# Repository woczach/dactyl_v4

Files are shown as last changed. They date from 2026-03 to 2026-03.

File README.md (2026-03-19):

# Dactyl v4

Custom split ergonomic keyboard project based on a Dactyl Manuform-style shell, adapted around a flexible main PCB, a custom thumb cluster, and trackball support.

This repository contains the KiCad design files, printable case parts, and reference images used during the build.

## Overview

This project is my own Dactyl-style keyboard design. The main board is a custom flexible PCB, while the extra keys and thumb-cluster approach were informed by an existing open hardware reference.

Design references used for this build:

- Dactyl Manuform base shape and layout:
[ryanis.cool keyboard link](https://ryanis.cool/cosmos/beta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)
  
- Extra keys for thumb-cluster:
  [MxLEDBitPCB](https://github.com/swanmatch/MxLEDBitPCB/blob/master/readme_en.md)

## Gallery

### 3D keyboard visualization

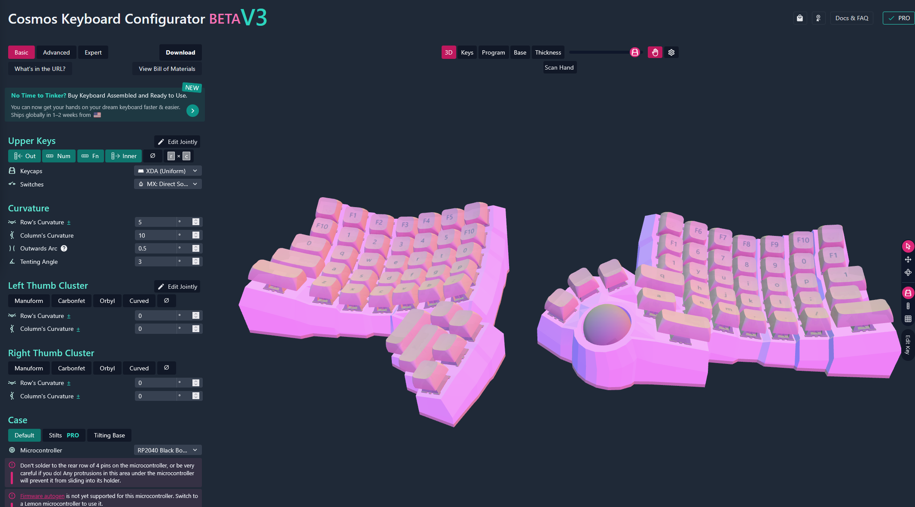
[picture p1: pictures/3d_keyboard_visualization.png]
3D keyboard visualization


### Main flexible PCB

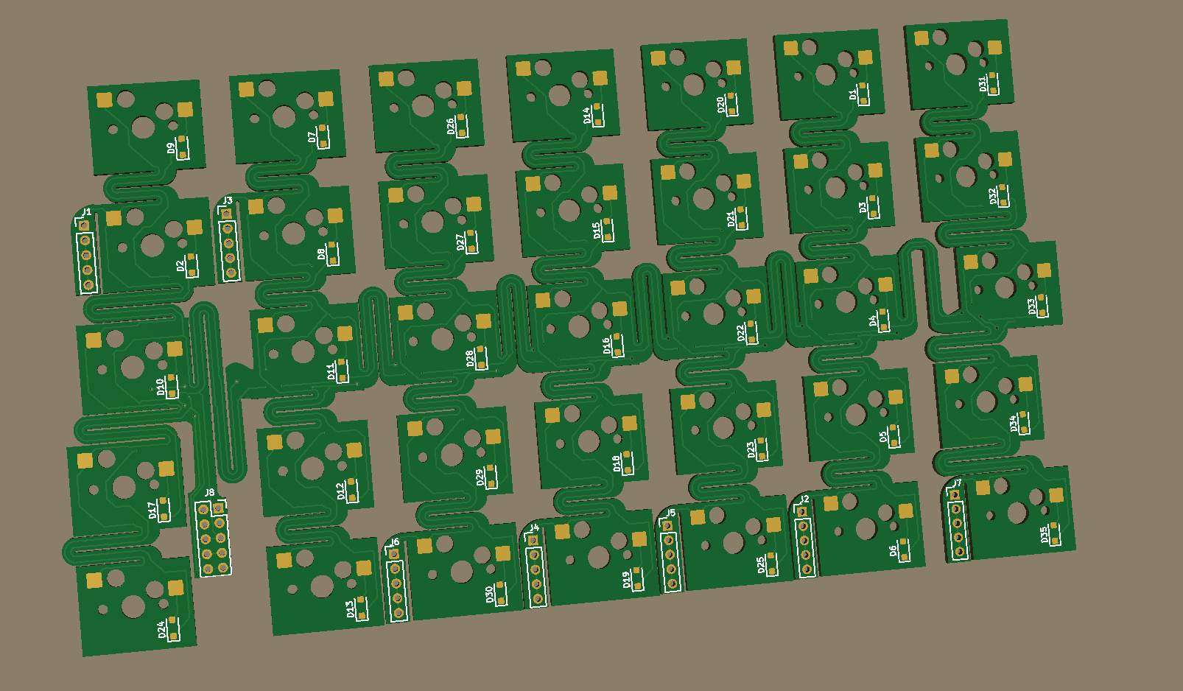
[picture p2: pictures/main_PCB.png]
Main PCB


### Extra keys / thumb cluster reference

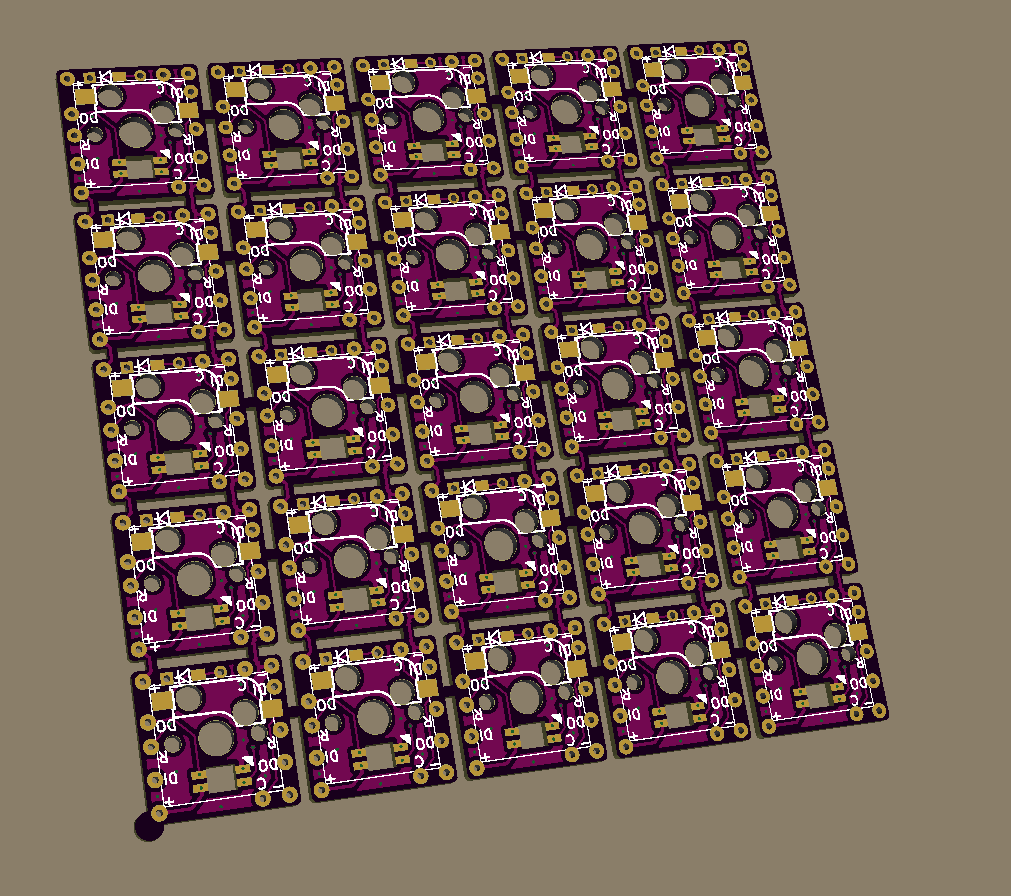
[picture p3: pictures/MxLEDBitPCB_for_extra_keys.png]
MxLEDBitPCB reference for extra keys


## Repository Contents

- `dactyl_v4/3dForm/printfiles/` contains the printable case, plate, and holder STL files.
- `dactyl_v4/Kicad/flex/` contains the main KiCad project for the flexible PCB design.
- `pictures/` contains reference renders and PCB images used in this README.

## Hardware Summary

- Split ergonomic Dactyl-style keyboard
- Custom flexible main PCB
- Separate thumb / extra-key area inspired by MxLEDBitPCB
- Trackball support using a PMW3360 or PMW3389 sensor
- Dual RP2040 controller setup with TRRS interconnect

## Bill of Materials

Prices below reflect the sourced parts actually purchased for this build. Items not covered by that list are left blank.

| Category | Item | Qty | Notes | Total |
| --- | --- | ---: | --- | ---: |
| Keys and switches | Womier Retro Brown Gray PBT keycap set | 1 | 138-key Cherry-profile set | 51.39 PLN |
| Keys and switches | PBTfans Doppelganger 40s kit | 1 | Child kit, 40s | 77.19 PLN |
| Keys and switches | MX-compatible switches | 90 | Outemu Silent Cream Yellow Pro, bought as one 90-pack | 71.19 PLN |
| Keys and switches | 1N4148 diodes | 100 | 1N4148W T4 SOD-123, bought as one 100-pack | 5.72 PLN |
| Pointing device and mechanical parts | 34 mm trackball | 1 | GBALL34RN, purple | 47.79 PLN |
| Pointing device and mechanical parts | PMW3360 or PMW3389 sensor | 1 | PMW3389 module | 69.19 PLN |
| Pointing device and mechanical parts | 3 x 6 x 2.5 mm bearings | 5 | Bought as one 5-pack | 9.41 PLN |
| Pointing device and mechanical parts | 3 x 8 mm dowel pins | 10 | M3, bought as one 10-pack | 4.90 PLN |
| Pointing device and mechanical parts | Tindie-supported PCB for sensor assembly | 1 | Use a compatible board as required by the sensor setup |  |
| Electrical | RP2040 Black Board USB-C | 2 | Aliexpress boards |  |
| Electrical | PJ-320A TRRS connectors | 10 | Bought as one 10-pack | 6.29 PLN |
| Electrical | TRRS cable | 1 | 3.5 mm TRRS spring coiled cable, 90-degree male-to-male | 13.99 PLN |
| Electrical | Flexible PCB fabrication | 1 | Main flex PCB, converted from 30 USD | 110.61 PLN |
| Electrical | Extra PCB fabrication | 1 | Auxiliary PCB, converted from 2 USD | 7.37 PLN |
| Electrical | Kailh hot-swap sockets | 3 | 40-piece packs, CPG1511 | 45.03 PLN |
| Electrical | SK6812MINI-E LEDs | 1 | 100-piece lot | 34.89 PLN |
| Electrical | Wire-wrap or magnet wire spool | 1 | Internal wiring |  |
| Mounting | M3 x 6 mm flat head screws | 18 | Bottom plate and microcontroller holder |  |
| Mounting | M3 x 8 mm flat head screws | 2 | Microcontroller holder through bottom plate |  |
| Mounting | M3 screw inserts | 20 | Heat-set or press-fit, depending on print and process |  |
| Other parts | 3D print service | 1 | Case and related printed parts | 100.00 PLN |

**Summary price:** 654.96 PLN

## Attribution

This repository is a custom project, but it explicitly builds on ideas and references from the following sources:

- Ryanis Cosmos for the Dactyl Manuform base geometry and layout exploration
- Swanmatch MxLEDBitPCB for ideas around extra keys and thumb-cluster implementation

The main board design in this repository is my own custom flexible PCB adaptation.

## License

This repository is distributed under the license included in [LICENSE](LICENSE).

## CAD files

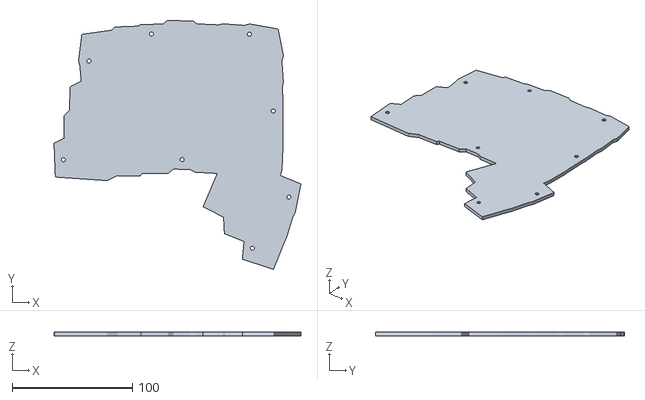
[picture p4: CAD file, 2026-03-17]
dactyl_v4/3dForm/printfiles/woboard_v4-plateleft.stl
205.4 x 206.9 x 3.00

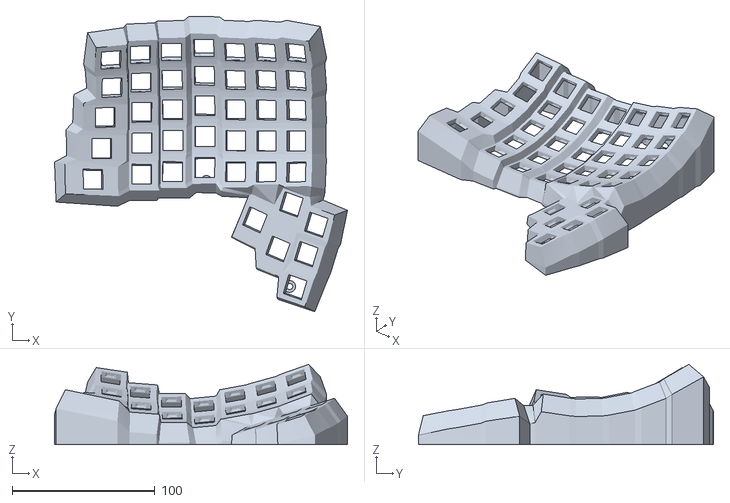
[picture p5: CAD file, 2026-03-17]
dactyl_v4/3dForm/printfiles/woboard_v4-caseleft.stl
205.4 x 206.9 x 56.3

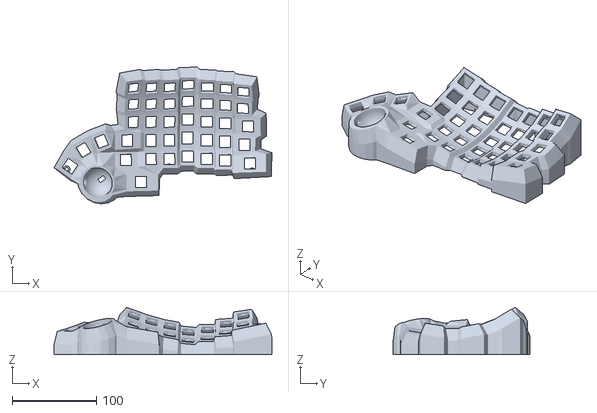
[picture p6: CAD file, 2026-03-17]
dactyl_v4/3dForm/printfiles/woboard_v4-caseright.stl
259.4 x 162.7 x 56.3

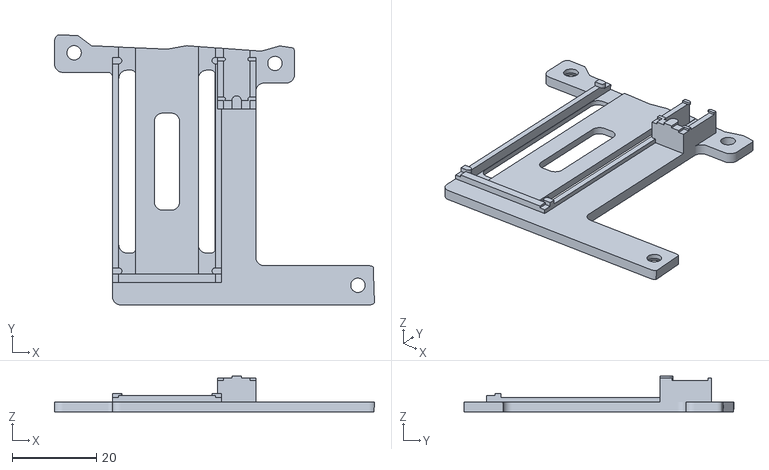
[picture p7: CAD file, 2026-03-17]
dactyl_v4/3dForm/printfiles/woboard_v4-holderleft.stl
75.8 x 63.9 x 8.50

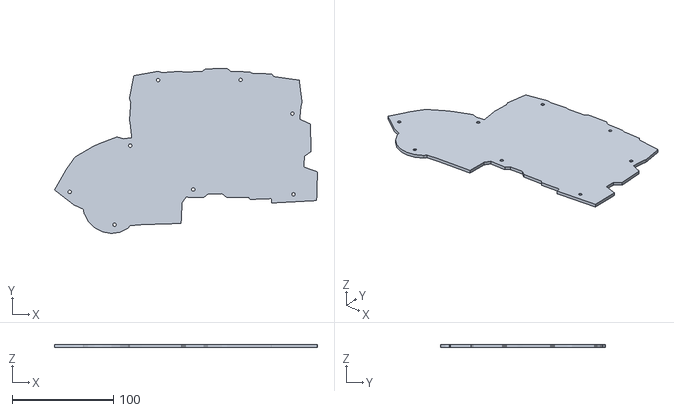
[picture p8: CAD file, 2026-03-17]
dactyl_v4/3dForm/printfiles/woboard_v4-plateright.stl
259.4 x 162.7 x 3.00

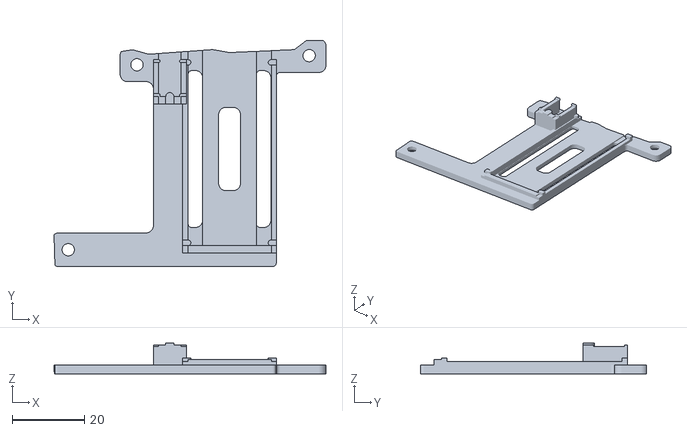
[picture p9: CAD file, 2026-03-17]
dactyl_v4/3dForm/printfiles/woboard_v4-holderright.stl
75.1 x 62.5 x 8.50

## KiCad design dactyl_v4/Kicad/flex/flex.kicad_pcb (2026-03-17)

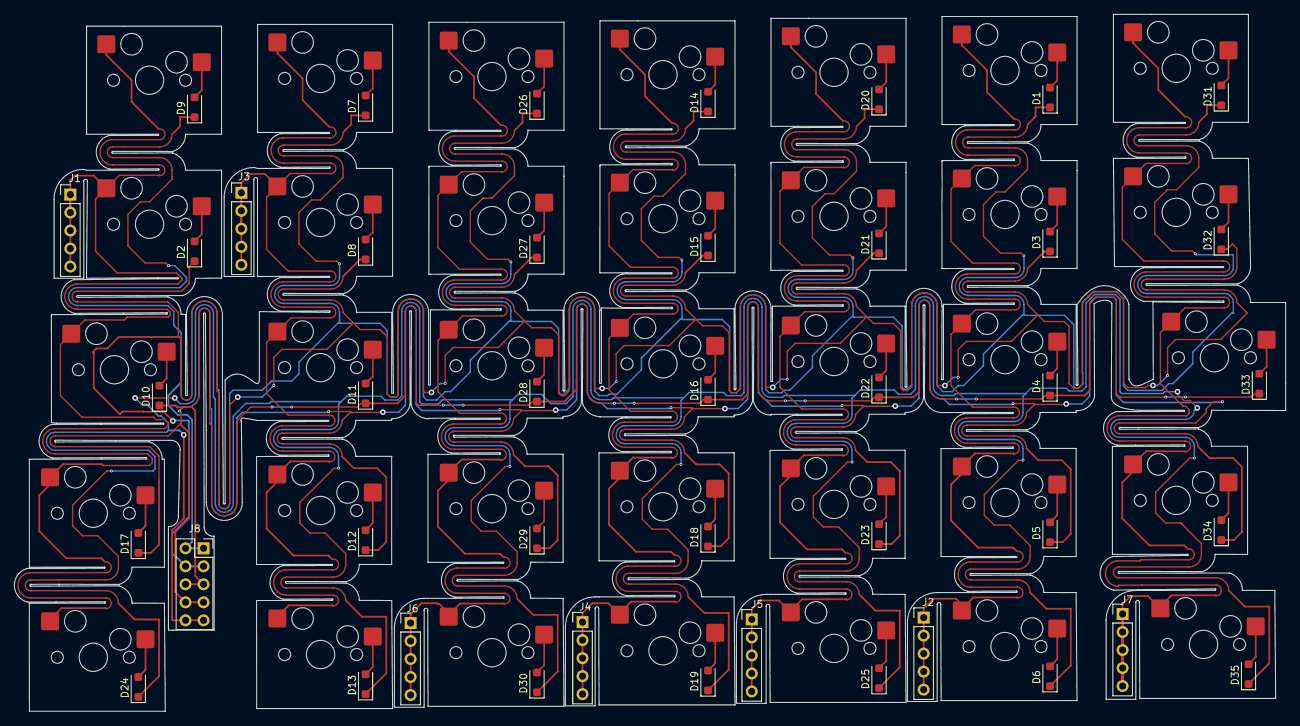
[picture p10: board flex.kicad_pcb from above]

Board: 2 copper layers, 179.4 x 98.3 mm, 78 parts (0 on the bottom side), 47 nets.

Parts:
D1, D2, D3, D4, D5, D6, D7, D8, D9, D10, D11, D12, D13, D14, D15, D16, D17, D18, D19, D20, D21, D22, D23, D24, D25, D26, D27, D28, D29, D30, D31, D32, D33, D34, D35: D; D_SOD-123F
J1, J2, J3, J4, J5, J6, J7: Conn_01x05; PinHeader_1x05_P2.54mm_Vertical
J8: Conn_02x05_Counter_Clockwise; PinSocket_2x05_P2.54mm_Vertical
SW1, SW2, SW3, SW4, SW5, SW6, SW7, SW8, SW9, SW10, SW11, SW12, SW13, SW14, SW15, SW16, SW17, SW18, SW19, SW20, SW21, SW22, SW23, SW24, SW25, SW26, SW27, SW28, SW29, SW30, SW31, SW32, SW33, SW34, SW35: SW_Push; MX100H

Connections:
COL1: J1.1, J1.2, J1.3, J1.4, J1.5, SW2.1, SW9.1, SW10.1, SW17.1, SW24.1
COL2: J2.1, J2.2, J2.3, J2.4, J2.5, SW1.1, SW3.1, SW4.1, SW5.1, SW6.1
COL3: J3.1, J3.2, J3.3, J3.4, J3.5, SW7.1, SW8.1, SW11.1, SW12.1, SW13.1
COL4: J4.1, J4.2, J4.3, J4.4, J4.5, SW14.1, SW15.1, SW16.1, SW18.1, SW19.1
COL5: J5.1, J5.2, J5.3, J5.4, J5.5, SW20.1, SW21.1, SW22.1, SW23.1, SW25.1
COL6: J6.1, J6.2, J6.3, J6.4, J6.5, SW26.1, SW27.1, SW28.1, SW29.1, SW30.1
COL7: J7.1, J7.2, J7.3, J7.4, J7.5, SW31.1, SW32.1, SW33.1, SW34.1, SW35.1
unnamed: D1.2 (A), SW1.2
unnamed: D2.2 (A), SW2.2
unnamed: D3.2 (A), SW3.2
unnamed: D4.2 (A), SW4.2
unnamed: D5.2 (A), SW5.2
unnamed: D6.2 (A), SW6.2
unnamed: D7.2 (A), SW7.2
unnamed: D8.2 (A), SW8.2
unnamed: D9.2 (A), SW9.2
unnamed: D10.2 (A), SW10.2
unnamed: D11.2 (A), SW11.2
unnamed: D12.2 (A), SW12.2
unnamed: D13.2 (A), SW13.2
unnamed: D14.2 (A), SW14.2
unnamed: D15.2 (A), SW15.2
unnamed: D16.2 (A), SW16.2
unnamed: D17.2 (A), SW17.2
unnamed: D18.2 (A), SW18.2
unnamed: D19.2 (A), SW19.2
unnamed: D20.2 (A), SW20.2
unnamed: D21.2 (A), SW21.2
unnamed: D22.2 (A), SW22.2
unnamed: D23.2 (A), SW23.2
unnamed: D24.2 (A), SW24.2
unnamed: D25.2 (A), SW25.2
unnamed: D26.2 (A), SW26.2
unnamed: D27.2 (A), SW27.2
unnamed: D28.2 (A), SW28.2
unnamed: D29.2 (A), SW29.2
unnamed: D30.2 (A), SW30.2
unnamed: D31.2 (A), SW31.2
unnamed: D32.2 (A), SW32.2
unnamed: D33.2 (A), SW33.2
unnamed: D34.2 (A), SW34.2
unnamed: D35.2 (A), SW35.2
ROW1: D1.1 (K), D7.1 (K), D9.1 (K), D14.1 (K), D20.1 (K), D26.1 (K), D31.1 (K), J8.1, J8.2
ROW2: D2.1 (K), D3.1 (K), D8.1 (K), D15.1 (K), D21.1 (K), D27.1 (K), D32.1 (K), J8.3, J8.4
ROW3: D4.1 (K), D10.1 (K), D11.1 (K), D16.1 (K), D22.1 (K), D28.1 (K), D33.1 (K), J8.5, J8.6
ROW4: D5.1 (K), D12.1 (K), D17.1 (K), D18.1 (K), D23.1 (K), D29.1 (K), D34.1 (K), J8.7, J8.8
ROW5: D6.1 (K), D13.1 (K), D19.1 (K), D24.1 (K), D25.1 (K), D30.1 (K), D35.1 (K), J8.9, J8.10

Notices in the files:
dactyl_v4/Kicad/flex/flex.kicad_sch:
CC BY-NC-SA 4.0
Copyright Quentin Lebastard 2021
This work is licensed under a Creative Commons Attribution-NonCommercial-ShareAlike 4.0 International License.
